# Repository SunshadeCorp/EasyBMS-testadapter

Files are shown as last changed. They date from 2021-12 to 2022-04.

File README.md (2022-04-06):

# EasyBMS Testadapter
PCB of the EasyBMS testadapter for end of line test as an EAGLE project

Used design rules from [here](https://github.com/JLCPCB/jlcpcb-eagle) with one modification: under "Masks" in DRC settings, set "Limit" to 20mil to cover vias that have smaller drill size with solder mask.

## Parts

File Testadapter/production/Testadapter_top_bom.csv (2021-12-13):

Comment | Designator | Footprint | LCSC Part #
2k2 | R27 R28 | R0805
10k | R13 R14 R15 R16 R19 R20 R21 R22 R23 R24 R25 R26 | R0805
100R | R1 R2 R3 R4 R5 R6 R7 R8 R9 R10 R11 R12 | R0805
680R | R17 R18 | R0805
C2286 | LED1 | CHIP-LED0603
C8062 | D1 D2 | MELF-MLL34
C8492 | T1 T2 | SOT-23
C8545 | T3 T4 | SOT-23
C72043 | LED2 | CHIP-LED0603

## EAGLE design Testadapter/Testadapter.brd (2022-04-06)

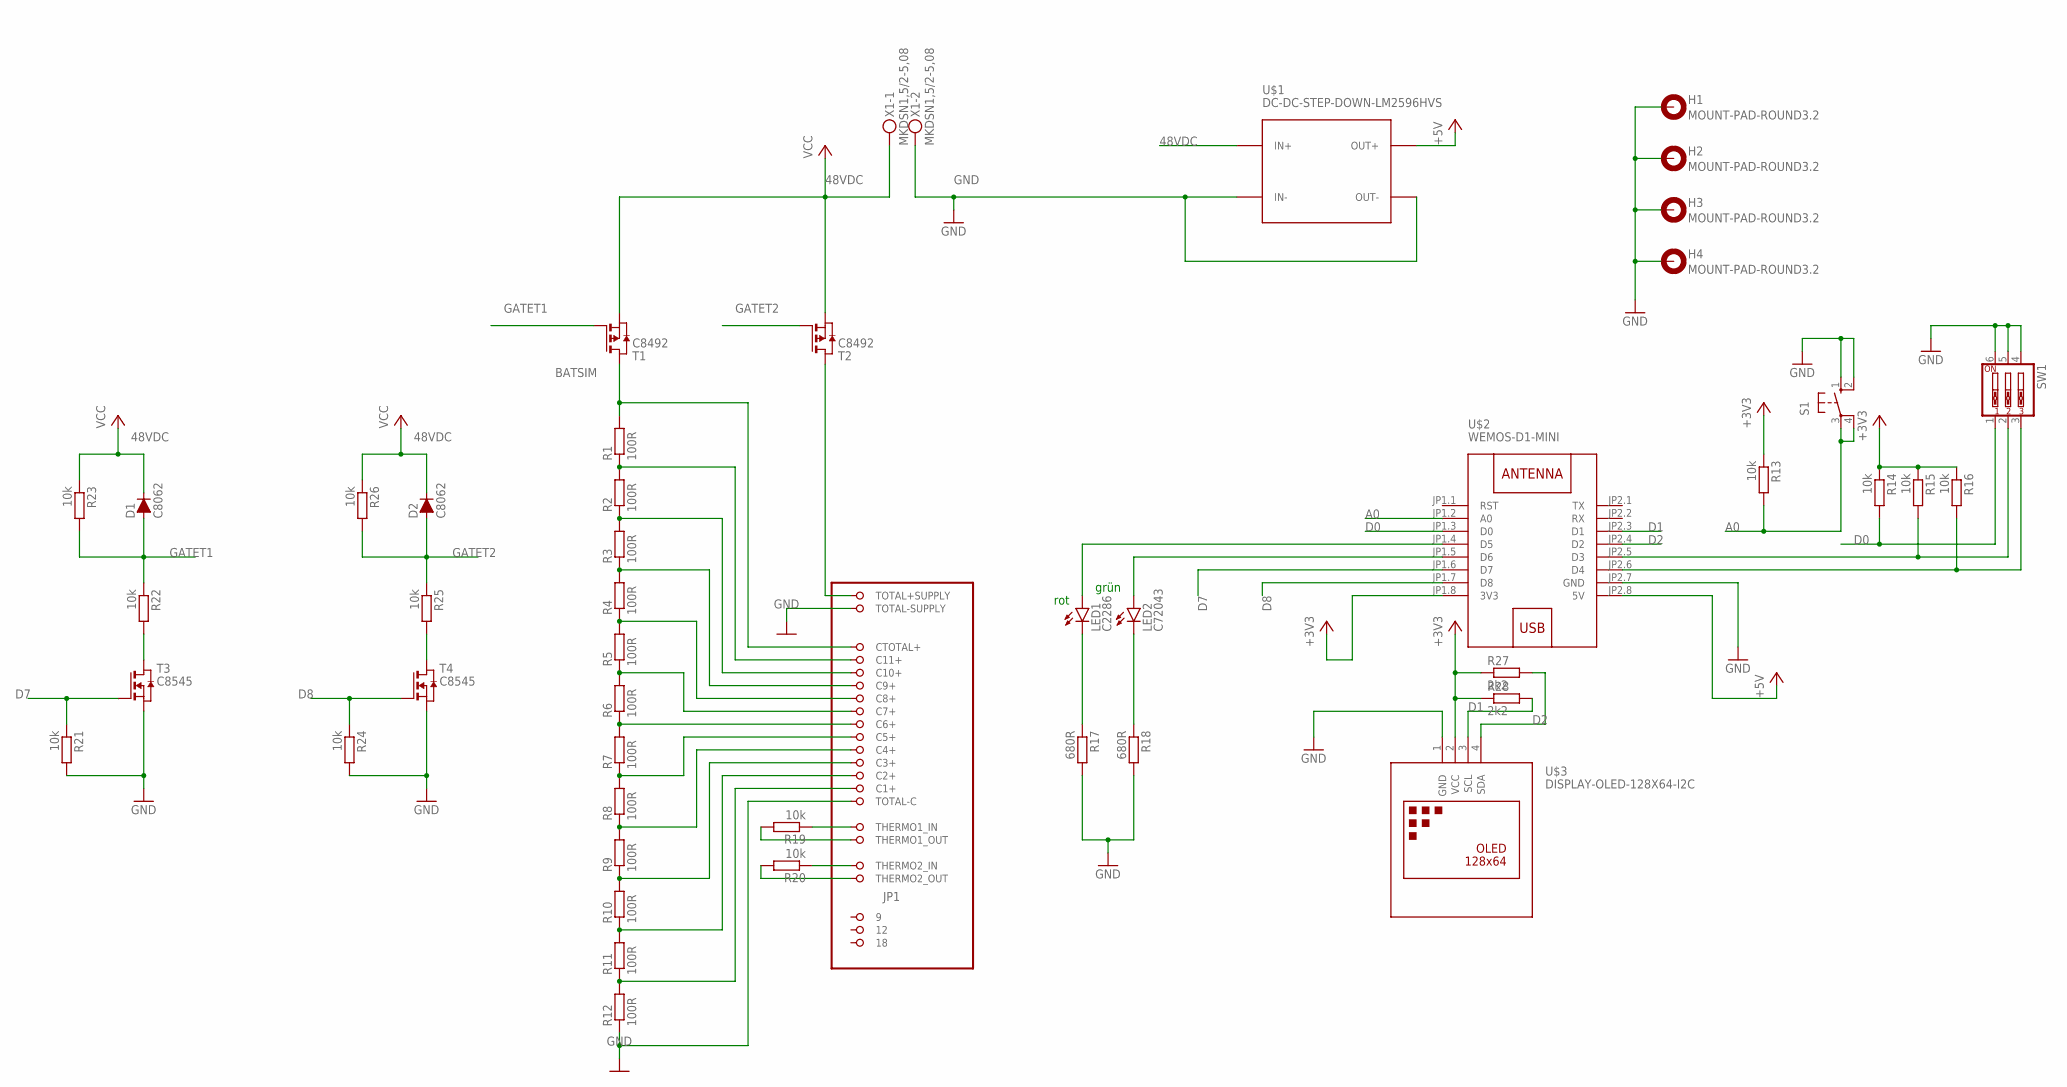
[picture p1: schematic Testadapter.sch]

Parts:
D1, D2: C8062; MELF-MLL34
H1, H2, H3, H4: MOUNT-PAD-ROUND3.2; 3,2-PAD
JP1: PINHD-2X11_MEB12S_MODULSEITE_SMD; 2X11_MEB12S_MODULSEITE_SMD
LED1: C2286; CHIP-LED0603
LED2: C72043; CHIP-LED0603
R1, R2, R3, R4, R5, R6, R7, R8, R9, R10, R11, R12: 100R; R0805
R13, R14, R15, R16, R19, R20, R21, R22, R23, R24, R25, R26: 10k; R0805
R17, R18: 680R; R0805
R27, R28: 2k2; R0805
S1: 10-XX; B3F-10XX
SW1: SW_DIP-3; EDG-03
T1, T2: C8492; SOT-23
T3, T4: C8545; SOT-23
U$1: DC-DC-STEP-DOWN-LM2596HVS
U$2: WEMOS-D1-MINI
U$3: DISPLAY-OLED-128X64-I2C
X1: MKDSN1,5/2-5,08

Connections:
48VDC: D1.1 (C), D2.1 (C), R23.1, R26.1, T1.2 (S), T2.2 (S), U$1.IN+, X1.1
+3V3: R13.1, R14.1, R15.1, R16.1, R27.1, R28.1, U$2.JP1.8 (3V3), U$3.2 (VCC)
+5V: U$1.OUT+, U$2.JP2.8 (5V)
A0: R13.2, S1.3, S1.4 (P1), U$2.JP1.2 (A0)
BATSIM: JP1.21 (CTOTAL+), R1.2, T1.1 (D)
D0: R14.2, SW1.1, U$2.JP1.3 (D0)
D1: R28.2, U$2.JP2.3 (D1), U$3.3 (SCL)
D2: R27.2, U$2.JP2.4 (D2), U$3.4 (SDA)
D7: R21.1, T3.3 (G), U$2.JP1.6 (D7)
D8: R24.1, T4.3 (G), U$2.JP1.7 (D8)
GATET1: D1.2 (A), R22.1, R23.2, T1.3 (G)
GATET2: D2.2 (A), R25.1, R26.2, T2.3 (G)
GND: H1.B3,2, H2.B3,2, H3.B3,2, H4.B3,2, JP1.7 (TOTAL-SUPPLY), JP1.9 (TOTAL-C), R12.1, R17.2, R18.2, R21.2, R24.2, S1.1 (S), S1.2 (S1), SW1.4, SW1.5, SW1.6, T3.2 (S), T4.2 (S), U$1.IN-, U$1.OUT-, U$2.JP2.7 (GND), U$3.1 (GND), X1.2
unnamed: JP1.20 (C11+), R1.1, R2.2
unnamed: JP1.19 (C10+), R2.1, R3.2
unnamed: JP1.18 (C9+), R3.1, R4.2
unnamed: JP1.17 (C8+), R4.1, R5.2
unnamed: JP1.16 (C7+), R5.1, R6.2
unnamed: JP1.15 (C6+), R6.1, R7.2
unnamed: JP1.14 (C5+), R7.1, R8.2
unnamed: JP1.13 (C4+), R8.1, R9.2
unnamed: JP1.12 (C3+), R9.1, R10.2
unnamed: JP1.11 (C2+), R10.1, R11.2
unnamed: JP1.10 (C1+), R11.1, R12.2
unnamed: R15.2, SW1.2, U$2.JP2.5 (D3)
unnamed: R16.2, SW1.3, U$2.JP2.6 (D4)
unnamed: LED1.C, R17.1
unnamed: LED2.C, R18.1
unnamed: JP1.22 (TOTAL+SUPPLY), T2.1 (D)
unnamed: LED2.A, U$2.JP1.5 (D6)
unnamed: LED1.A, U$2.JP1.4 (D5)
unnamed: R22.2, T3.1 (D)
unnamed: R25.2, T4.1 (D)
THERMO1IN: JP1.1 (THERMO1_IN), R19.1
THERMO1OUT: JP1.3 (THERMO1_OUT), R19.2
THERMO2_IN: JP1.2 (THERMO2_IN), R20.1
THERMO2_OUT: JP1.4 (THERMO2_OUT), R20.2

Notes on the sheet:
rot
grün

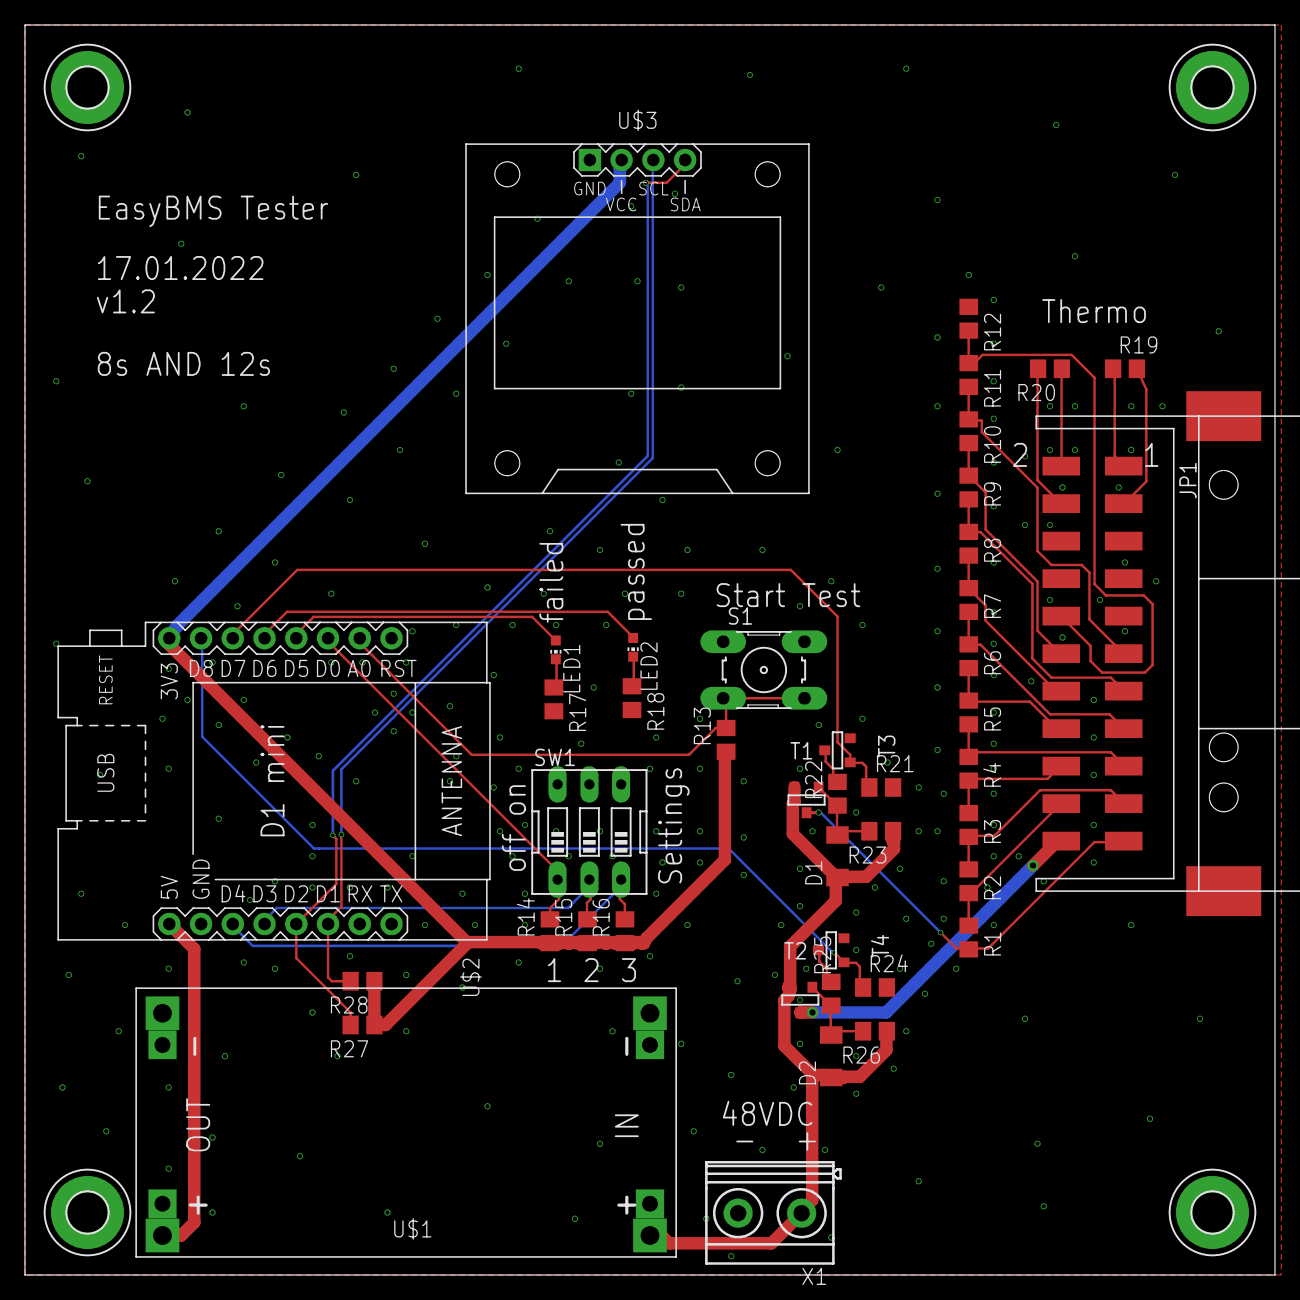
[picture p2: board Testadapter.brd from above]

Board: 2 copper layers, 100.0 x 100.0 mm, 47 parts (0 on the bottom side), 37 nets.

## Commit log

2021-12-03 Initial commit, copied from EasyBMS_Hardware repo
    [testbench.brd, testbench.sch]
2021-12-12 routing and placement updated, dimensions changed
    [testbench.brd, testbench.sch]
2021-12-13 display added
    [testbench.brd, testbench.sch]
2021-12-13 routing updated
    [testbench.brd, testbench.sch]
2021-12-13 text added
    [testbench.brd]
2021-12-13 text added and diodes defined
    [testbench.brd, testbench.sch]
2021-12-13 gerber files added
    [testbench_top_bom.csv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]
2021-12-13 layout slightly change, new revision
    [testbench.brd]
2022-01-16 fixed PFETs reverse orientation, v1.2
    [testbench.brd, testbench.sch]
2022-01-17 sample stepsequence running
2022-01-18 updated library with SMD footprint of BMS connector
2022-01-18 added description on footprints
2022-01-18 new smd footprint of BMS connector integrated
    [testbench.brd, testbench.sch]
2022-02-05 Added derived mqtt broker class and subscribed bms topics
2022-04-06 apply new folder structure, renamed files, stripped EAGLE lib for MEB connectors
    [Testadapter.brd, Testadapter.sch, Testadapter_top_bom.csv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]
2022-04-06 changed design rules to cover vias with solder mask and updated README accordingly
    [Testadapter.brd]

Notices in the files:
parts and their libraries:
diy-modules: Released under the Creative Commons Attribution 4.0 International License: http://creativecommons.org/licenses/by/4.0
